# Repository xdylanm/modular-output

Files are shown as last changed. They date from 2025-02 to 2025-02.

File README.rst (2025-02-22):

Output Module
========================

An audio output module for Eurorack, combining two mono input channels into a stereo output with a panning mixer. The stereo output is suitable to drive headphones or small speakers.

Features
--------

* Two input channels (A and B) with the second normaled to the first. 
* Independent input level adjustments for both channels
* Stereo panning mixer
* Level indicator (red indicates :math:`V_{pp} \gtrapprox 9V`)
* Output volume control
* LM386 output amplifiers

References
----------

#. Ray Wilson, "Stereo Mixer" `MFOS <https://musicfromouterspace.com/analogsynth_new/STEREOMIXER2006/STEREOMIXER2006.php>`_
#. Elliot Williams, "You Can Have My LM386s When You Pry Them From My Cold Dead Hands" `Hackaday <https://hackaday.com/2016/12/07/you-can-have-my-lm386s-when-you-pry-them-from-my-cold-dead-hands/>`_
#. "Mixer", `Befaco <https://www.befaco.org/mixer-2/>`_

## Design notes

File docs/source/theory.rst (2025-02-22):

Theory of Operation
===================

The Output module accepts line signals (10Vpp) at the inputs. With :math:`R=100\mathrm{k}\Omega`, the input impedance ranges from :math:`R||R_i` to :math:`R`. The gain of the input stage is :math:`A_i = -\frac{R_f}{R_i}`. Gain options include 2.2 (:math:`R_i = 100k\Omega`, :math:`R_f=220k\Omega`), 4.5 (:math:`R_i=47k\Omega`, :math:`R_f=220k\Omega`) or 10 (:math:`R_i=47k\Omega`, :math:`R_f=470k\Omega` per MFOS).

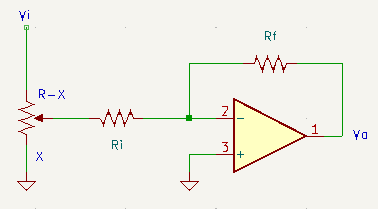
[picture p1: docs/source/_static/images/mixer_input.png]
Mixer input


At the output of the input gain stage, the panning network sends the signal to the line out buffers and stereo out amplifiers on the left and right channels. Here, the lower fixed :math:`R` also acts as the input resistance for the inverting summing amplifier (line out buffering), and :math:`V_{o(l|r)} = -\frac{R_{fo}}{R}\left(V_{i(l|r)1} + V_{i(l|r)2}\right)`. With the variable resistor :math:`R` for panning, the voltages :math:`V_{ir}` and :math:`V_{il}` will be in the range :math:`0 \leq V_{i(r|l)} \leq \frac{V_i}{3}`, so an output stage gain of 3 will restore the signal level.   

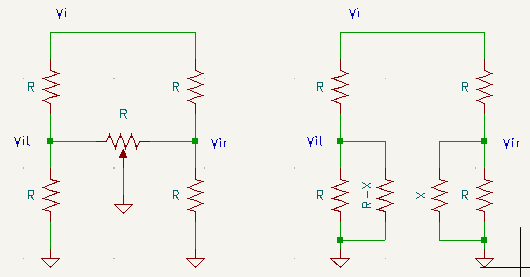
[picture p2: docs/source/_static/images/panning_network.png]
Panning network


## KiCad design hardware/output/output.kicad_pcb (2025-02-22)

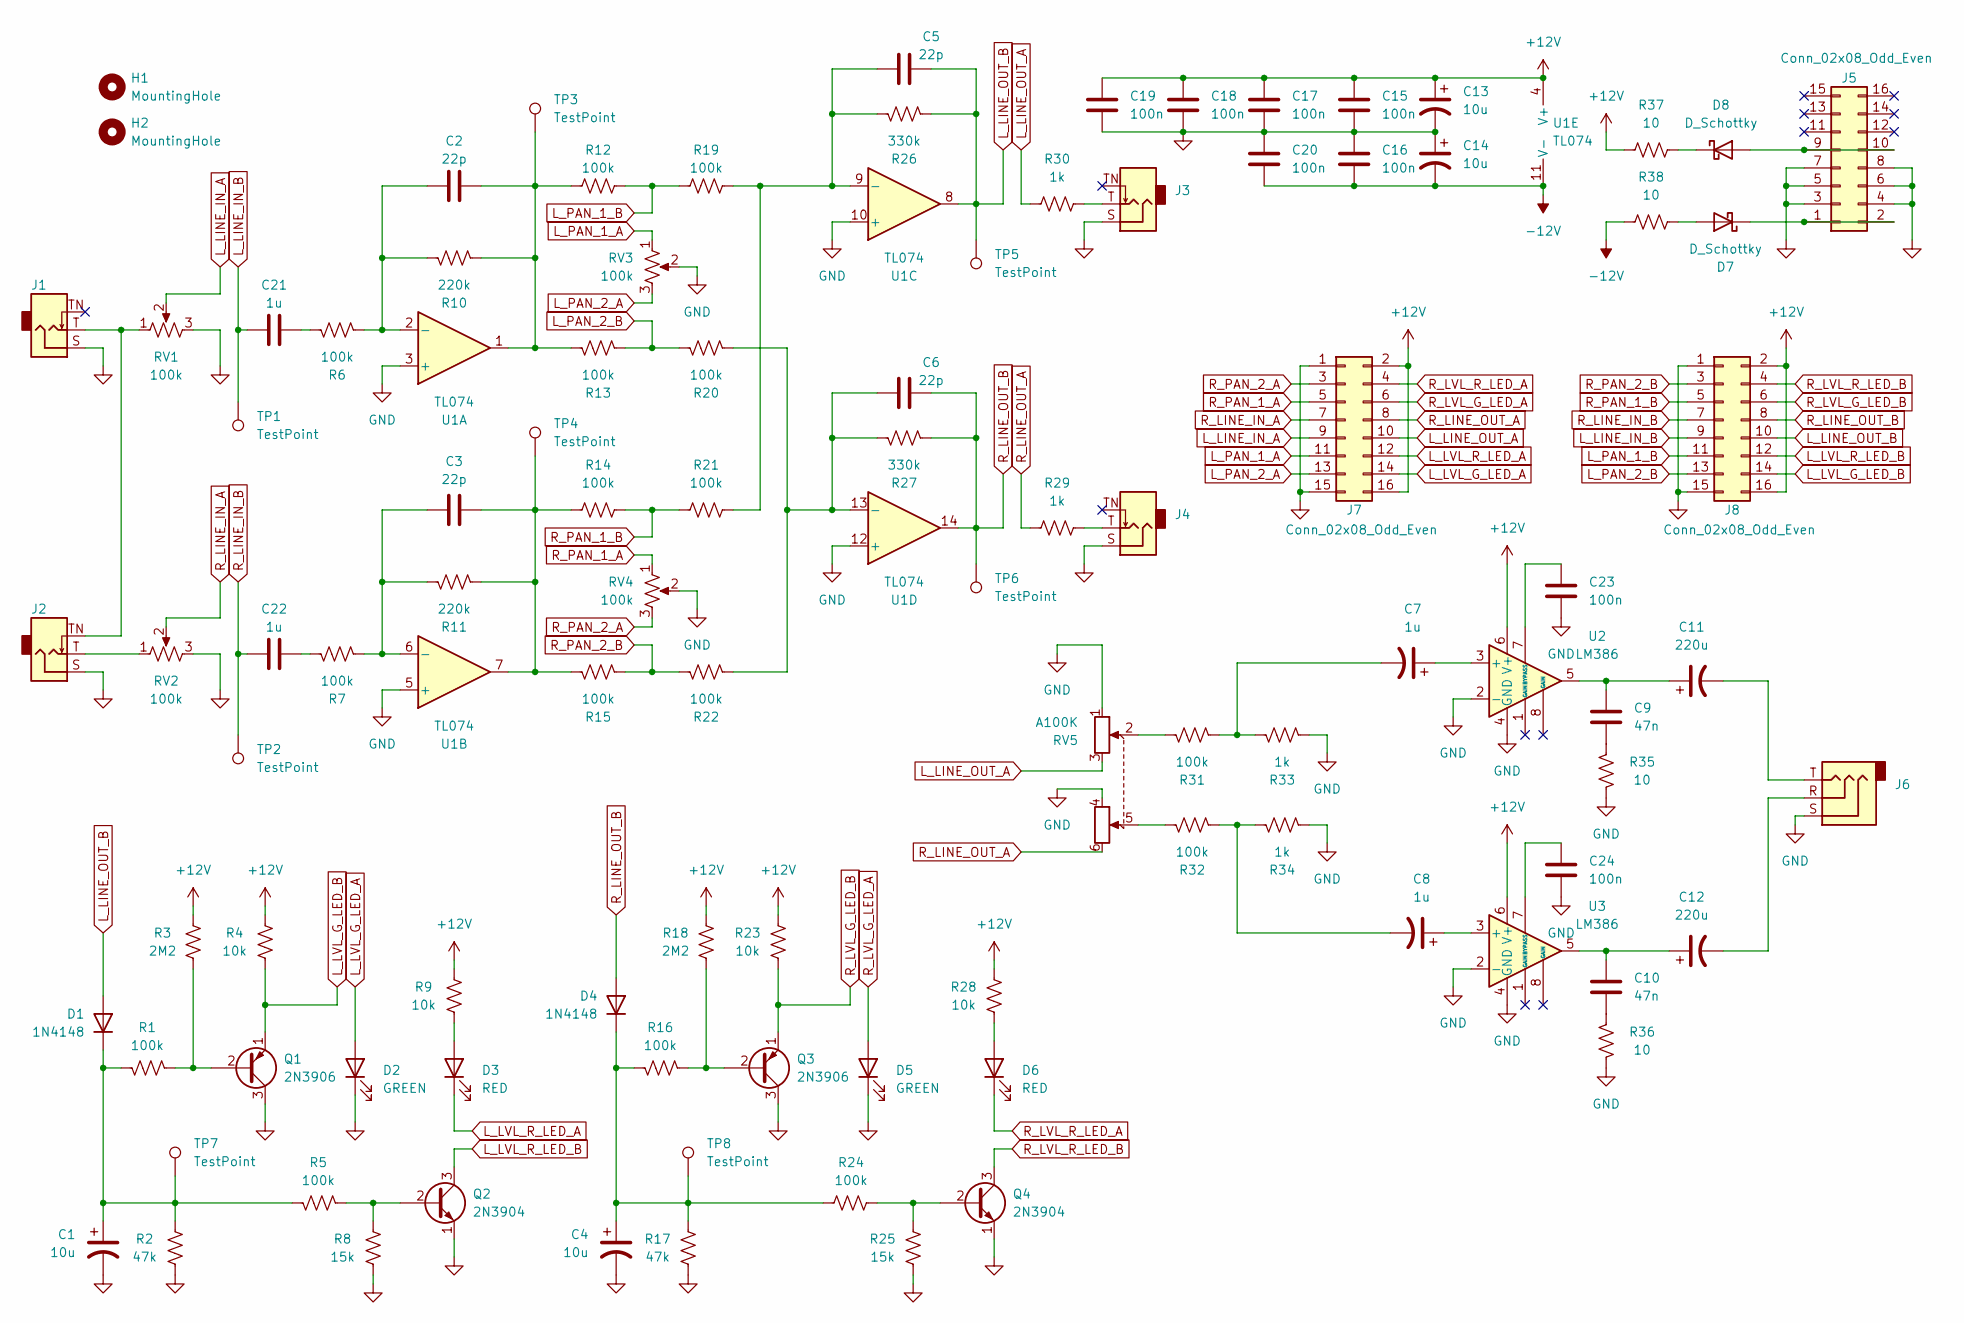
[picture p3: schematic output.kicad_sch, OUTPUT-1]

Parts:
C1, C4, C13, C14: 10u; CP_Radial_D4.0mm_P2.00mm
C2, C3, C5, C6: 22p; C_Disc_D5.0mm_W2.5mm_P2.50mm
C7: 1u; C_Disc_D5.0mm_W2.5mm_P5.00mm
C8, C21, C22: 1u; C_Disc_D5.0mm_W2.5mm_P2.50mm
C9, C10: 47n; C_Disc_D5.0mm_W2.5mm_P2.50mm
C11, C12: 220u; CP_Radial_D6.3mm_P2.50mm
C15, C16, C17, C18, C23, C24: 100n; C_Disc_D5.0mm_W2.5mm_P2.50mm
C19, C20: 100n; C_Disc_D5.0mm_W2.5mm_P5.00mm
D1: 1N4148; D_DO-35_SOD27_P7.62mm_Horizontal
D2, D5: GREEN; LED_D3.0mm_Clear
D3, D6: RED; LED_D3.0mm_Clear
D4: 1N4148; D_DO-35_SOD27_P2.54mm_Vertical_AnodeUp
D7, D8: D_Schottky; D_DO-41_SOD81_P7.62mm_Horizontal
H1, H2: MountingHole; MountingHole_3.2mm_M3_DIN965
J1, J2, J3, J4: AudioJack2_SwitchT; Jack_3.5mm_QingPu_WQP-PJ301M-12_Vertical
J5: Conn_02x08_Odd_Even; IDC-Header_2x08_P2.54mm_Vertical
J6: AudioJack3; Jack_3.5mm_QingPu_WQP-PJ301CM_Vertical
J7, J8: Conn_02x08_Odd_Even; PinHeader_2x08_P2.54mm_Vertical_ThinPad
Q1, Q3: 2N3906; TO-92_Inline_Wide
Q2, Q4: 2N3904; TO-92_Inline_Wide
R1, R5, R7, R12, R13, R15, R16, R19, R20, R21, R24, R31, R32: 100k; R_Axial_DIN0204_L3.6mm_D1.6mm_P2.54mm_Vertical
R2, R17: 47k; R_Axial_DIN0204_L3.6mm_D1.6mm_P2.54mm_Vertical
R3, R18: 2M2; R_Axial_DIN0204_L3.6mm_D1.6mm_P2.54mm_Vertical
R4, R9, R23, R28: 10k; R_Axial_DIN0204_L3.6mm_D1.6mm_P2.54mm_Vertical
R6, R14, R22: 100k; R_Axial_DIN0207_L6.3mm_D2.5mm_P7.62mm_Horizontal
R8, R25: 15k; R_Axial_DIN0204_L3.6mm_D1.6mm_P2.54mm_Vertical
R10, R11: 220k; R_Axial_DIN0204_L3.6mm_D1.6mm_P2.54mm_Vertical
R26, R27: 330k; R_Axial_DIN0204_L3.6mm_D1.6mm_P2.54mm_Vertical
R29, R30, R33, R34: 1k; R_Axial_DIN0204_L3.6mm_D1.6mm_P2.54mm_Vertical
R35, R36: 10; R_Axial_DIN0204_L3.6mm_D1.6mm_P2.54mm_Vertical
R37, R38: 10; R_Axial_DIN0207_L6.3mm_D2.5mm_P7.62mm_Horizontal
RV1, RV2, RV3, RV4: 100k; Potentiometer_Bourns_PTV09A-1_Single_Vertical
RV5: A100K; Potentiometer_Bourns_PTV112-4_Dual_Vertical
TP1, TP2, TP3, TP4, TP5, TP6, TP7, TP8: TestPoint; PinHeader_1x01_P2.54mm_Vertical
U1: TL074; DIP-14_W7.62mm_Socket
U2, U3: LM386; DIP-8_W7.62mm_Socket

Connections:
+12V: C13.1, C15.2, C17.2, C18.2, C19.2, J7.2, J7.16, J8.2, J8.16, R3.2, R4.2, R9.2, R18.2, R23.2, R28.2, R37.1, U1.4 (V+), U2.6 (V+), U3.6 (V+)
-12V: C14.2, C16.1, C20.1, R38.1, U1.11 (V-)
GND: C1.2, C4.2, C13.2, C14.1, C15.1, C16.2, C17.1, C18.1, C19.1, C20.2, C23.2, C24.2, D2.1 (K), D5.1 (K), J1.S, J2.S, J3.S, J4.S, J5.3, J5.4, J5.5, J5.6, J5.7, J5.8, J6.S, J7.1, J7.15, J8.1, J8.15, Q1.3 (C), Q2.1 (E), Q3.3 (C), Q4.1 (E), R2.1, R8.1, R17.1, R25.1, R33.2, R34.2, R35.1, R36.1, RV1.3, RV2.3, RV3.2, RV4.2, RV5.1, RV5.4, U1.3 (+), U1.5 (+), U1.10 (+), U1.12 (+), U2.2 (-), U2.4 (GND), U3.2 (-), U3.4 (GND)
L_LINE_IN_A: J7.9, RV1.2
L_LINE_IN_B: C21.1, J8.9, TP1.1
L_LINE_OUT_A: J7.10, R30.1, RV5.3
L_LINE_OUT_B: C5.2, D1.2 (A), J8.10, R26.2, TP5.1, U1.8
L_LVL_G_LED_A: D2.2 (A), J7.14
L_LVL_G_LED_B: J8.14, Q1.1 (E), R4.1
L_LVL_R_LED_A: D3.1 (K), J7.12
L_LVL_R_LED_B: J8.12, Q2.3 (C)
L_PAN_1_A: J7.11, RV3.1
L_PAN_1_B: J8.11, R12.2, R19.1
L_PAN_2_A: J7.13, RV3.3
L_PAN_2_B: J8.13, R13.2, R20.1
unnamed: C2.2, R10.2, R12.1, R13.1, TP3.1, U1.1
unnamed: C3.2, R11.2, R14.1, R15.1, TP4.1, U1.7
unnamed: C7.2, R31.2, R33.1
unnamed: C8.2, R32.2, R34.1
unnamed: C9.2, R35.2
unnamed: C10.1, C12.1, U3.5
unnamed: C10.2, R36.2
unnamed: C9.1, C11.1, U2.5
unnamed: C11.2, J6.T
unnamed: C12.2, J6.R
unnamed: C21.2, R6.1
unnamed: C22.2, R7.1
unnamed: C1.1, D1.1 (K), R1.2, R2.2, R5.2, TP7.1
unnamed: D3.2 (A), R9.1
unnamed: C4.1, D4.1 (K), R16.2, R17.2, R24.1, TP8.1
unnamed: D6.2 (A), R28.1
unnamed: D7.2 (A), R38.2
unnamed: D7.1 (K), J5.1, J5.2
unnamed: D8.2 (A), J5.9, J5.10
unnamed: D8.1 (K), R37.2
unnamed: J1.T, J2.TN, RV1.1
unnamed: J2.T, RV2.1
unnamed: J3.T, R30.2
unnamed: J4.T, R29.2
unnamed: Q1.2 (B), R1.1, R3.1
unnamed: Q2.2 (B), R5.1, R8.2
unnamed: Q3.2 (B), R16.1, R18.1
unnamed: Q4.2 (B), R24.2, R25.2
unnamed: R31.1, RV5.2
unnamed: R32.1, RV5.5
unnamed: C2.1, R6.2, R10.1, U1.2 (-)
unnamed: C3.1, R7.2, R11.1, U1.6 (-)
unnamed: C5.1, R19.2, R21.2, R26.1, U1.9 (-)
unnamed: C6.1, R20.2, R22.2, R27.1, U1.13 (-)
unnamed: C7.1, U2.3 (+)
unnamed: C23.1, U2.7 (BYPASS)
unnamed: C8.1, U3.3 (+)
unnamed: C24.1, U3.7 (BYPASS)
R_LINE_IN_A: J7.7, RV2.2
R_LINE_IN_B: C22.1, J8.7, TP2.1
R_LINE_OUT_A: J7.8, R29.1, RV5.6
R_LINE_OUT_B: C6.2, D4.2 (A), J8.8, R27.2, TP6.1, U1.14
R_LVL_G_LED_A: D5.2 (A), J7.6
R_LVL_G_LED_B: J8.6, Q3.1 (E), R23.1
R_LVL_R_LED_A: D6.1 (K), J7.4
R_LVL_R_LED_B: J8.4, Q4.3 (C)
R_PAN_1_A: J7.5, RV4.1
R_PAN_1_B: J8.5, R14.2, R21.1
R_PAN_2_A: J7.3, RV4.3
R_PAN_2_B: J8.3, R15.2, R22.1

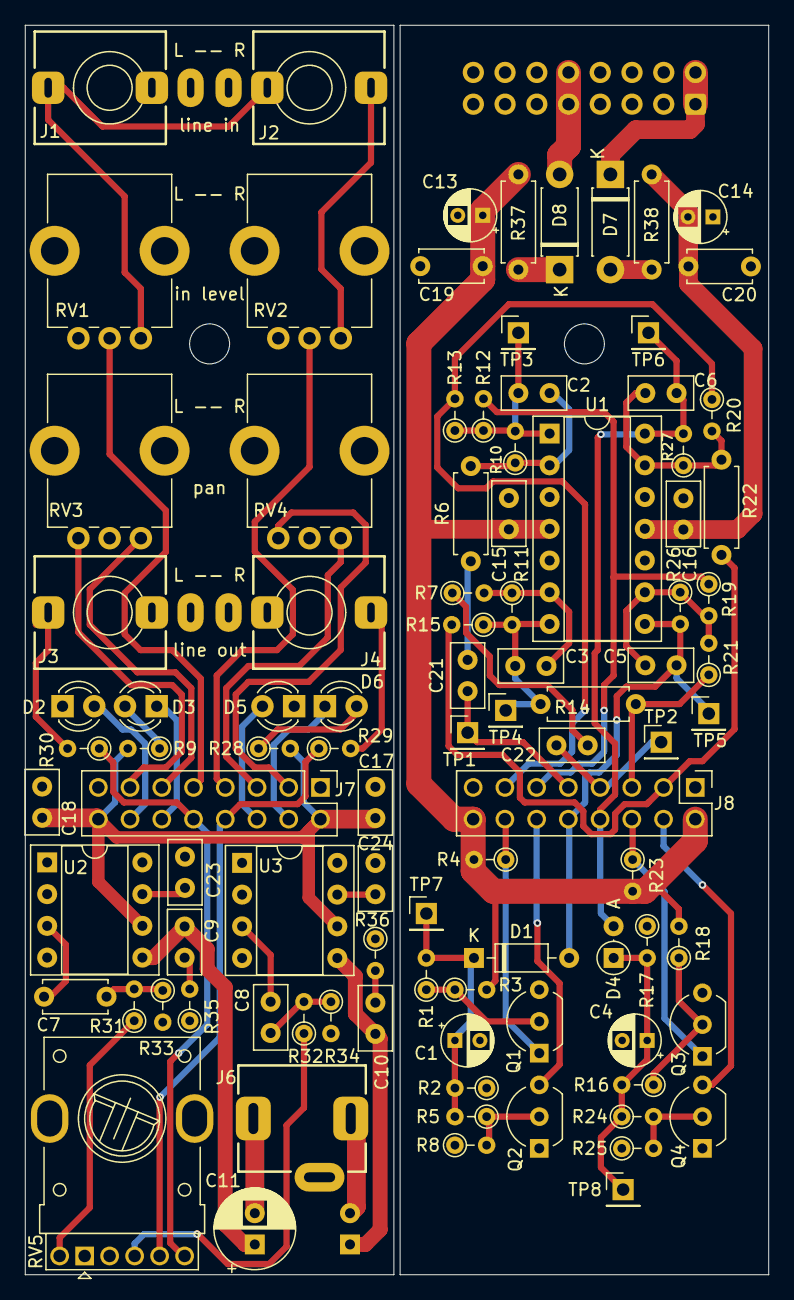
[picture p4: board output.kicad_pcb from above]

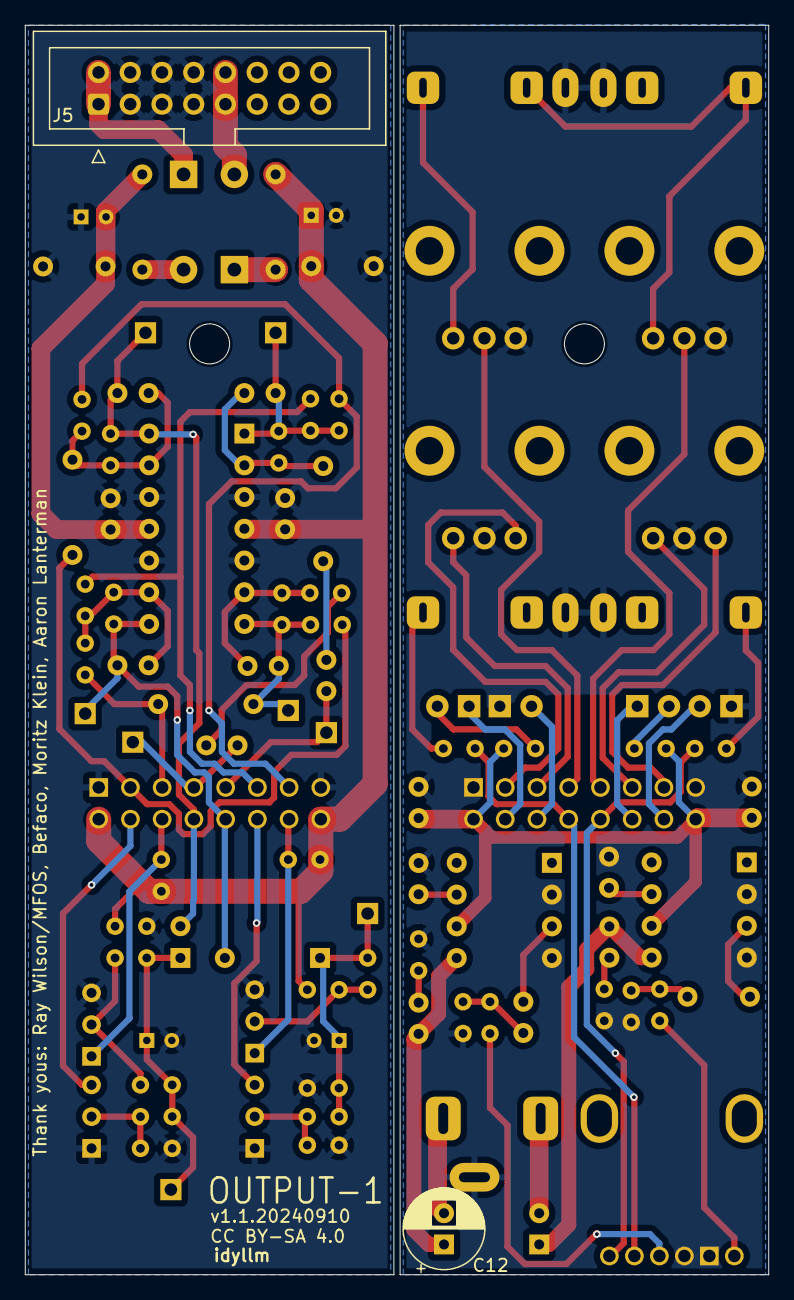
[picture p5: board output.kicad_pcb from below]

Board: 2 copper layers, 59.5 x 100.0 mm, 100 parts (2 on the bottom side), 65 nets.

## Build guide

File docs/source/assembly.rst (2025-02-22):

Assembly Guide
==============

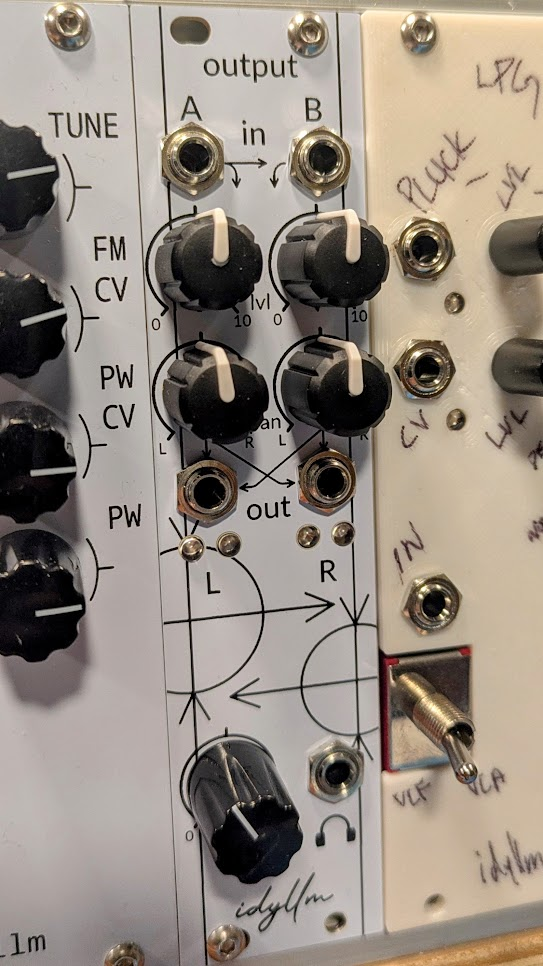
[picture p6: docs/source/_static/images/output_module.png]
Output module


Backplane
---------

Starting with the backplane board (with power input header), place and solder the flat-laying components

* D7, D8
* R37, R38 (may substitute ferrite bead or wire for both)
* R6, R22, R14
* D1, D4 (placed vertically)

Next, place and solder the socket for U1.

Place and solder the ceramic capacitors

* C2, C3, C5, C6
* C15, C16, C19, C20
* C21, C22

Next, place and solder the vertically-oriented 100k resistors

* R7, R12, R13, R15, R19, R20, R21

Place and solder the remaining vertically-oriented resistors near U1

* R10, R11
* R26, R27

Place and solder the remaining vertically-oriented resistors in the level meter stages (near Q1-Q4)

* R1, R5, R16, R24
* R2, R17
* R3, R18
* R4, R23
* R8, R25

Next, place and solder the BJTs

* Q1, Q3
* Q2, Q4

Place and solder the electrolytic capacitors

* C1, C4, C13, C14

Finally, place and solder the headers

* J8
* J5 (back side)

Optionally add the test point headers.

Frontplane
----------

Start by placing and soldering the sockets for U2 and U3.

Next, place and solder the ceramic capacitors,

* C7, C8
* C9, C10
* C17, C18, C23, C24

Place and solder the vertically-oriented resistors near U2 and U3

* R31, R32
* R33, R34
* R35, R36

Place and solder the pin header J7, oriented to the back of the board (attaches to J8).

Next, place and solder the remaining vertically-oriented resistors

* R4, R23
* R29, R30

Place and solder the audio jacks. Check the fit of the face plate before finalizing

* J1, J2, J3, J4
* J6 (may need to trim the standoff tabs to ensure all audio jacks are at the same height)

Place and solder the output coupling electrolytic capacitors. C11 sits on the top of the board and C12 is placed on the back side. Ensure that the leads are left sufficiently long so that C11 and C12 can be bent to a horizontal orientation and do not extend past the edge of the board.

Place and solder the potentiometers. Check the fit of the face plate before finalizing.

* RV1, RV2, RV3, RV4
* RV5

With the face plate temporarily installed, position and solder the red and green level LEDs. The LEDs should protrude slightly through the openings in the face plate.

* D2, D5
* D3, D6

Finishing 
---------

Install the ICs. On the backplane, insert U1. On the frontplane, insert U2 and U3.

Add the standoff on the backplane and connect the frontplane and backplane. Finish the build by attaching the face plate using the audio jack bushings.

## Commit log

2025-02-22 Copying the module over from the 'toolbox' and adding documentation
    [output.kicad_pcb, output.kicad_sch, output_a.kicad_pcb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]
2025-10-03 Converted project to MkDocs/Material
2025-10-03 Fixed links, added schematic to nav bar

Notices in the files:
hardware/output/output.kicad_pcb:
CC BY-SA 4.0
